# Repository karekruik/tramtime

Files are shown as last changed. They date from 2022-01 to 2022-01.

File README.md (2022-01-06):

# Tramtime 🚋
Tramtime

### IoT for displaying public transport times

## What does it do? 

Displays the time and line number of the coming next two public transport at a certain stop and going to a certain destination by using Google Directions API and Google Cloud Functions API. 

## Main Components

* Wemos d1 mini

* E-ink screen

* 18650 battery

* TP4056 charger

* Step up converter

* 3D printed enclosure

## Why Google Directions API?

I originally wanted to use a local public transport API (9292.nl) but they turned out to be not free. So I signed up for Google Directions API which gives you a free credit and free request (under limit) every month. 

## Why Google Functions API?

Google Directions API delivers back a json file. It is really long and I cannot parse it with Wemos d1 mini (insufficient RAM). Because I did not have a better dev board with higher RAM (e.g. ESP32) at the moment of developing this project, I went through with Google Functions API to parse this data. 

## What is included in this repository?

* Wemos d1 mini sketch (tested in Arduino IDE) 

* Python code for Google Functions API

* STEP and STL files for the enclosure (3D print) 

## Summary of the functions

### Hardware
* E-ink screen => Wemos d1 mini > step-up converter > TP4056 charger > 18650 battery

* USB micro port for charging the battery

* Reset button for Wemos d1 mini

* Wemos D1 mini

https://www.bitsandparts.nl/WeMos-D1-mini-ESP8266-WiFi-ontwikkelboard-p122268

* E-INK Screen : WaveShare 1.54" e-Paper Module 200x200

https://www.robotshop.com/nl/en/154-e-paper-module-200x200.html

* TP4056 (second generation)

https://www.bitsandparts.nl/Oplader-voor-LiIon-LiPoly-batterijen-accus-MicroUSB-TP4056-p111752

* Step-up DC-DC converter (this component is not a must. I used it to get a longer run time)

https://www.tinytronics.nl/shop/en/power/voltage-converters/boost-(step-up)-converters/mini-dc-dc-5v-step-up-boost-converter-480ma

* Reset button (tall)

https://www.tinytronics.nl/shop/en/switches/manual-switches/pcb-switches/tactile-pushbutton-switch-momentary-4pin-6*6*9mm

### Software flow

* Wemos d1 mini connects to a prescribed WIFI
* Sends a request to Google Functions API (GFAPI)
* GFAPI gets the next two tram times and line numbers from Google Directions API (GDAPI)
* GFAPI returns the retrieved info back to Wemos d1 mini
* Wemos d1 mini parses this info and prints it to the E-ink display
* Wemos d1 mini goes to deep sleep and wakes up 5 minutes before the next tram time to check the times again for a fresh update in case of any delay
* Wemos d1 wakes up and this loop restarts

Disclaimer: I know it is an overengineered solution until I learn to do better.

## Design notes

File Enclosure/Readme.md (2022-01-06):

Assembly.step file gives the impression of the assembly fitting.

Other three STL files are for 3D printing.

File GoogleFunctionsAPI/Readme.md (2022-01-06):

### These two files (requirements.txt and main.py) are placed to Google Functions API

Don't forget to update the personal API key and other parameters (destination and location place IDs) in main.py

Set the **TRIGGER** > Trigger Type > HTTP in Google Functions API (Current Wemos sketch does not work with HTTPS)

Set **Runtime, build, connections and security settings**  > Connections > Allow all traffic

Set **Permissions** > Cloud Function invokder > Allusers

Tip: Set trigger alarms for Google Cloud Budget for being informed of any exceedence of limits before being charged by surprise.

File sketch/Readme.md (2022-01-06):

### List of required libraries for the sketch 

include <Arduino.h>

include <ESP8266WiFi.h>

include <ESP8266WiFiMulti.h>

include <ESP8266HTTPClient.h>

include <WiFiClient.h>

include <GxEPD.h>

include <GxGDEH0154D67/GxGDEH0154D67.h>  // 1.54" b/w 

include GxEPD_BitmapExamples

include <Fonts/FreeMonoBold24pt7b.h>

include <Fonts/FreeMonoBold9pt7b.h>

include <Fonts/FreeMonoBold12pt7b.h>

include <Fonts/FreeMonoBold18pt7b.h>

include <GxIO/GxIO_SPI/GxIO_SPI.h>

include <GxIO/GxIO.h>

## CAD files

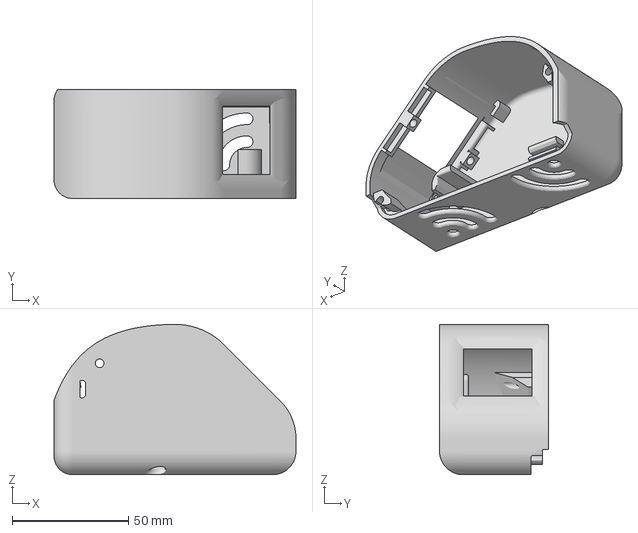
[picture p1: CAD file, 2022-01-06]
Enclosure/Body1.3mf
104.0 x 46.8 x 64.6 mm

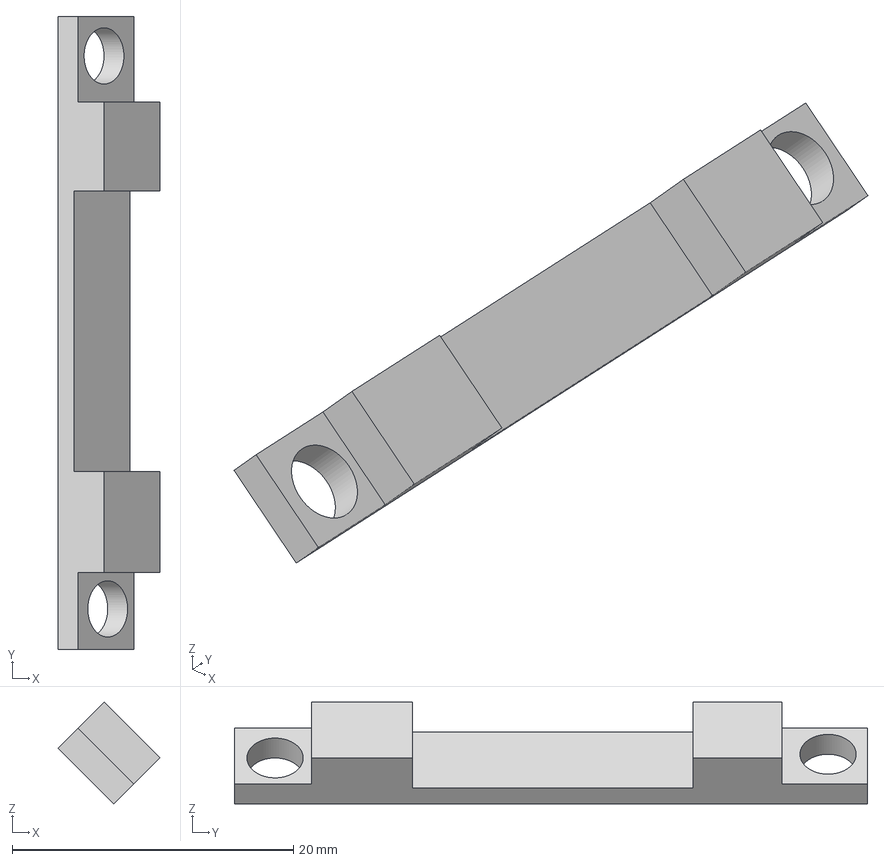
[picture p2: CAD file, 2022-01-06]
Enclosure/Body3.3mf
7.25 x 45.0 x 7.25 mm

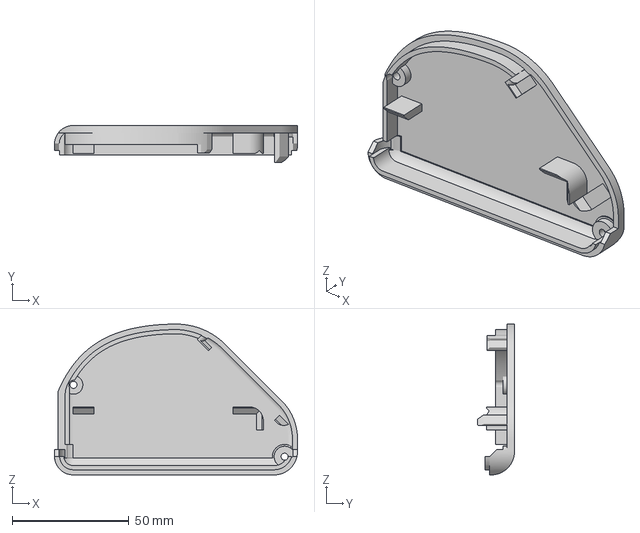
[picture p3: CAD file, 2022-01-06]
Enclosure/Body2.3mf
104.0 x 15.8 x 64.6 mm

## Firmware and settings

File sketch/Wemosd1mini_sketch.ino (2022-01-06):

#include <Arduino.h>
#include <ESP8266WiFi.h>
#include <ESP8266WiFiMulti.h>
#include <ESP8266HTTPClient.h>
#include <WiFiClient.h>
ESP8266WiFiMulti WiFiMulti;

// screen > Wemos D1 mini
// BUSY -> D2, RST -> D4, DC -> D3, CS -> D8, CLK -> D5, DIN -> D7, GND -> GND, 3.3V -> 3.3V
 
// include library, include base class, make path known
#include <GxEPD.h>
#include <GxGDEH0154D67/GxGDEH0154D67.h>  // 1.54" b/w 
#include GxEPD_BitmapExamples

// FreeFonts from Adafruit_GFX
#include <Fonts/FreeMonoBold24pt7b.h>
#include <Fonts/FreeMonoBold9pt7b.h>
#include <Fonts/FreeMonoBold12pt7b.h>
#include <Fonts/FreeMonoBold18pt7b.h> 

#include <GxIO/GxIO_SPI/GxIO_SPI.h>
#include <GxIO/GxIO.h>
 
GxIO_Class io(SPI, /*CS=D8*/ SS, /*DC=D3*/ 0, /*RST=D4*/ 5); // 
GxEPD_Class display(io, /*RST=D4*/ 5, /*BUSY=D2*/ 4); // 

//
void setup() {
  Serial.begin(115200);
  //Serial.setDebugOutput(true);
  display.init(115200); // enable diagnostic output on Serial
  Serial.println();
//  for (uint8_t t = 4; t > 0; t--) {
//    Serial.printf("[SETUP] WAIT %d...\n", t);
//    Serial.flush();
  WiFi.mode(WIFI_STA);
  WiFiMulti.addAP("Wifi_name_here", "Wifi_password_here"); 
}

unsigned long t; //millisecond
unsigned long int_time_to_next_tram_2; 
String next_tram1 = "";
String next_tram2 = "";
void loop() {
  
  // wait for WiFi connection
    
  if ((WiFiMulti.run() == WL_CONNECTED)) {
    WiFiClient client;
    Serial.println("Wifi connected");
    HTTPClient http;
    // make sure you use HTTP address instead of HTTPS. Current code does not accept HTTPS
    if (http.begin(client, "Google_Functions_API_request_address_here  e.g.:http://xxxxxxxxxx.cloudfunctions.net/xxxxxxxxxxx")) { 
    // start connection and send HTTP header
      int httpCode = http.GET();
      // httpCode will be negative on error      
      Serial.print("http code: ");
      Serial.println(httpCode);
      // Sometimes Google Directions API does not work. 
      // Instead of Wemos to keep trying and wasting energy, let it sleep and try later.
      if (httpCode != 200) {
        Serial.println("HTTP code is not 200, sleeping 15 min before trying again");
        write2screenError("", &FreeMonoBold18pt7b);
        ESP.deepSleep(15e8); // sleep for 15 min
      }
      if (httpCode > 0) {
        // HTTP header has been sent and Server response header has been handled
        // file found at server
        if (httpCode == HTTP_CODE_OK || httpCode == HTTP_CODE_MOVED_PERMANENTLY) {
          String payload = http.getString();
          Serial.println(payload);
          
          // Check the payload's first three letters. If they are equal to "Now", then it comes from Google API
          // also it means Google API is running and result is valid
          // Otherwise sleep for 15 min to try again later
          if (payload.substring(0,3).equals("Now") == false) {
            Serial.println("Payload check: The data is not valid");
            Serial.println("Sleeping for 15 min");
            write2screenError("", &FreeMonoBold18pt7b);
            ESP.deepSleep(15e8); // sleep for 15 min
          }
          
          // parse payload          
          String now_text = separateString(payload, ',', 0);
          next_tram1 = separateString(payload, ',', 1);
          next_tram2 = separateString(payload, ',', 2);
          String time_to_next_tram_2 = separateString(payload, ',', 3);

          Serial.println("now_text:\t" + now_text);
          Serial.println("next_tram1:\t" + next_tram1);
          Serial.println("next_tram2:\t" + next_tram2);
          Serial.println("time_to_next_tram_2:\t" + time_to_next_tram_2);
          int_time_to_next_tram_2 = time_to_next_tram_2.toInt();
          
          unsigned long long sleep_duration; // in microsecond
          long sleep_duration_in_sec; // in second
          
          // time_to_next_tram_2 is in seconds. Wemos is put to sleep and woke up 5 min before the next_tram_2 departure time in case of any delay
          sleep_duration_in_sec = int_time_to_next_tram_2 - 300; //  seconds till wake-up

          // if sleep duration is longer than 3 hours, ESP is not able to sleep that long, therefore:
          // if sleep_duration_in_sec > 3 h, sleep 3 h
          if (sleep_duration_in_sec > 10800) { sleep_duration_in_sec = 10800 ;}
          
          // if duration is <0 then sleep only 5 min
          if (sleep_duration_in_sec < 300){
            Serial.println("Second tram is in less than 5 min");
            Serial.println("Sleeping only 5 min");
            sleep_duration_in_sec = 300;          
          }
          sleep_duration = sleep_duration_in_sec * 1e6; // sleep duration is microsecond 
          
          // Serial print sleep time
          Serial.print("sleep duration [us]:\t"); 
          Serial.println(sleep_duration); 
          Serial.print("sleep duration [s]:\t\t"); 
          Serial.println(sleep_duration_in_sec);
           
          // Print tram times to screen
          write2screen("", &FreeMonoBold24pt7b);

          // sleep
          ESP.deepSleep(sleep_duration);
        }
      } else {Serial.printf("[HTTP] GET... failed, error: %s\n", http.errorToString(httpCode).c_str());   }
      http.end();
    } else {Serial.printf("[HTTP} Unable to connect\n");}
    
    Serial.println("end of loop");
  }

  //t = millis();
  //while ( (millis() < t+2000)  ){
  //  yield();
  //}
}


// string separator tool
String separateString(String data, char separator, int index)
{
    int found = 0;
    int strIndex[] = { 0, -1 };
    int maxIndex = data.length() - 1;

    for (int i = 0; i <= maxIndex && found <= index; i++) {
        if (data.charAt(i) == separator || i == maxIndex) {
            found++;
            strIndex[0] = strIndex[1] + 1;
            strIndex[1] = (i == maxIndex) ? i+1 : i;
        }
    }
    return found > index ? data.substring(strIndex[0], strIndex[1]) : "";
}

// print text for tram times on e-ink display
void write2screen(const char name[], const GFXfont* f)
{
  display.setRotation(270);
  display.fillScreen(GxEPD_WHITE);
  display.setTextColor(GxEPD_BLACK);
  display.setFont(f);
  display.setCursor(0, 0);
  display.println();
  //display.println(name);
  display.println(separateString(next_tram1, ' ', 0)); 
  display.println(separateString(next_tram1, ' ', 1));
  display.println(separateString(next_tram2, ' ', 0)); 
  display.println(separateString(next_tram2, ' ', 1));
  display.update();
  delay(500);
}

// print text for error screen on e-ink display 
void write2screenError(const char name[], const GFXfont* f)
{
  display.setRotation(2);
  display.fillScreen(GxEPD_WHITE);
  display.setTextColor(GxEPD_BLACK);
  display.setFont(f);
  display.setCursor(0, 0);
  display.println();
  //display.println(name);
  display.println("Error."); 
  display.println("Sleeping 15 min");
  display.println("Will try again.");  
  display.update();
  delay(500);
}
